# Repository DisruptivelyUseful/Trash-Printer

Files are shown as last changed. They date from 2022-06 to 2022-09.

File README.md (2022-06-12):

# The Trash Printer
The Trash Printer is an open-source, low-cost, large-format 3D printer that prints directly from shredded plastic trash instead of filament.

It has been tested to work with shredded Polypropylene (#5) and Polyethylene (#2 and #4) which together make up over 50% of all household plastic waste. It uses a 1/4" (4.5mm) nozzle, which makes it VERY tolerant of dirt, labels, and adhesives, which are common in post-consumer waste streams.

The parts it makes are incredibly strong, light, and flexible, more comparable in terms of strength to parts made by traditional injection molding processes than those made by most desktop 3D printers. The better you clean your material, the better your prints will look, but if you're lazy like me, you can just throw your trash in without even cleaning it first. Skipping the filament-making step entirely reduces the recycling process to just two steps: Shred, and Print.

# Latest Stable Release
The Trash Printer has been in development for several years, but the most recent release, Version 3, is the first version to be fully open-source, and is easier and cheaper to build than the previous versions. This repository will be the home for the development of V3 onwards.

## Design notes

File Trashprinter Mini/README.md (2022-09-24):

This folder contains all of the unique info for building the Trashprinter Mini, based on the V3 of the Trashprinter.  The Mini uses a smaller cart, which is also available from [Harbor Freight](https://www.harborfreight.com/material-handling/hand-trucks-carts-dollies/service-carts/30-in-x-16-in-industrial-polypropylene-service-cart-58322.html).  All of the STL/SVG parts are the same as the original full-size V3. It's primarily the lead screws that will need to be cut to match the proportions of the smaller service cart frame.

We recently recorded video content showcasing the entire build process of the Mini version.  Edited video will be released in the future, but in the meantime, the raw video content can be seen on our twitch streams at [twitch.tv/DisruptivelyUseful](https://twitch.tv/disruptivelyuseful) and [twitch.tv/Drc3p0](https://twitch.tv/drc3p0)

* The extruder built during the livestream contained a 20mm x 35mm heater band.  [generic link for this part on amazon](https://www.amazon.com/LANGshaw-Stainless-30x25mm-30x30mm-Connector/dp/B0B6WMBQHR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).

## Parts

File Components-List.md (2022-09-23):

| QUANTITY	| 	COMPONENT NAME | LINK/INFO |
| ---- | --- | --- |
|1	|	Polypropylene Service Cart | I used this one from Harbor Freight: https://www.harborfreight.com/material-handling/hand-trucks-carts-dollies/service-carts/36-in-x-24-in-polypropylene-industrial-service-cart-58323.html and this one from Amazon might look nicer, but I haven't confirmed all the dimensions are the same, so proceed with caution: https://www.amazon.com/dp/B00FZ318KS?ref_=cm_sw_r_cp_ud_dp_696WCAM7XY2RMQK0P6MQ |
|1	|	Set of laser-cut or 3D printed parts | See the Build Files - STL or SVG |
| 1	|	15:1 Planetary Geared NEMA23 Stepper Motor | https://www.amazon.com/dp/B00WAV0N5E |
| 1	|	10' 1" OD Metal Tubing (2x24", 2x36") | Stainless Steel or Aluminum preferred. 3/4" EMT conduit will not work without modification of the hole sizes. |
| 4	|	T8 Z-axis Lead Screws | 2mm Pitch, 600mm |
| 2	|	T8 Y-axis Lead Screws | 2mm Pitch, 600mm |
| 1	|	T8 X-axis Lead Screw | 2mm Pitch, 700mm |
| 7	|	T8 Lead Nuts | https://www.amazon.com/gp/product/B079HQ386R |
| 1	|	Set of 4-wire spring connectors | https://www.amazon.com/dp/B08R6TFLHD |
| 1	|	Spool of 4-wire 22ga Stepper Wire | |
| 2	 | 	Series wiring kits from V1Engineering.com | |
| 2	 | 	10A Solid State Relay Modules | https://www.amazon.com/dp/B01N1MMSKI |
| 4	 | 	5/16" Threaded Rods |  |
| 4	 | 	5/16" Coupling Nuts |  |
| 1	 | 	50ct Box of 5/16" x 1" Bolts |  |
| 1	 | 	50ct Box of 5/16" Nuts |  |
| 1	 | 	Ultimaker Rambo v1.4 Control Board Kit |  |
| 1	 | 	Computer, Raspberry Pi, or Laptop | I'm using a Windows 10 Laptop, and if you aren't super confident with computers I'd recommend that, but a Raspberry Pi running Linux or a Mac or Linux laptop can definitely work, I just won't be able to explain exactly how. |
| 1	 | 	Arduino IDE Software |  |
| 1	 | 	Repetier-Host Software |  |
| 1	 | 	USB Extension Cable |  |
| 1	 | 	USB-B cable, 3ft or 6ft |  | https://www.amazon.com/gp/product/B076Z8J141 |
| 7	 | 	NEMA17 Stepper Motors |  https://www.amazon.com/gp/product/B00QEYADRQ |
| 7	 | 	5mm to 8mm Shaft Couplers | https://www.amazon.com/gp/product/B07DC2CV6T |
| 1	 | 	20-pack 608-2RS Bearings |https://www.amazon.com/gp/product/B07TWZ7X38 |
| 30	 | 	M3 Bolts x 20mm |  |
| 16	 | 	M3 Nuts, non-locking |  |
| 1	 | 	M4 x 30mm Bolts |  |
| 1	 | 	M4 Nuts, Nylon Locking |  |
| 8	 | 	5/16" x 2" Bolts | These should come with your service cart. |
| 1	 | 	PVC 3" Plumbing Wye |  |
| 2	 | 	24VDC Fans | https://www.amazon.com/gp/product/B0885XR31J |
| 1	 | 	24VDC 5A Power Supply | https://www.amazon.com/gp/product/B07K9HBHGR |
| 1	 | 	5.5" 3/4" NPT Brass Nipple | https://www.amazon.com/dp/B016Y8EB2E |
| 1	 | 	Gorilla Packing Tape | https://www.amazon.com/dp/B00MR6JWKY |
| 1	 | 	2M USB LED Strip, Warm White | https://www.amazon.com/dp/B08X1QMRKK |
| 1	 | 	Set of 3x 250-300C Cartridge Style Thermistors | https://www.amazon.com/gp/product/B07QDQXDQ5 |
| 1	 | 	35mm x 35mm 110V 380W Heater Band  | This heater works well for sliding over 3/4" NPT pipes and 1/2" NPT fittings. It can be used as a bulk heater or as a tip heater: https://www.amazon.com/gp/product/B075WNXLTY |
| 1	 | 	Set of Lever Lock Connectors | https://www.amazon.com/gp/product/B08QMLSMC6 |
| 1	 | 	10mm to 10mm Shaft Coupler | This is an inelegant but effective solution. I used only one half, and then laser cut a wooden spacer to fit the auger I wanted to use.https://www.amazon.com/gp/product/B078VSM9MG |

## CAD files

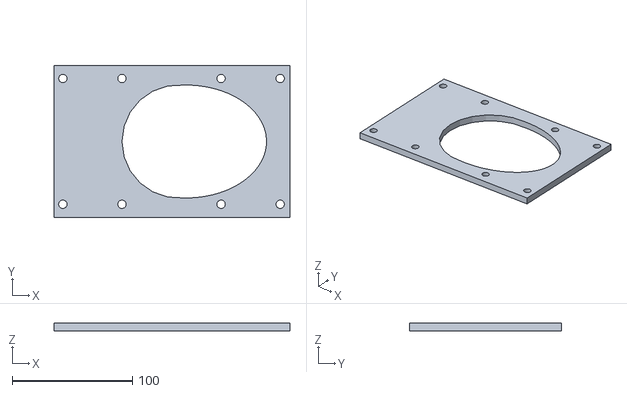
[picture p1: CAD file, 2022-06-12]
Build Files - STL/Trash Printer V3 - X Carriage Top Bracket.stl
196.6 x 126.4 x 6.35

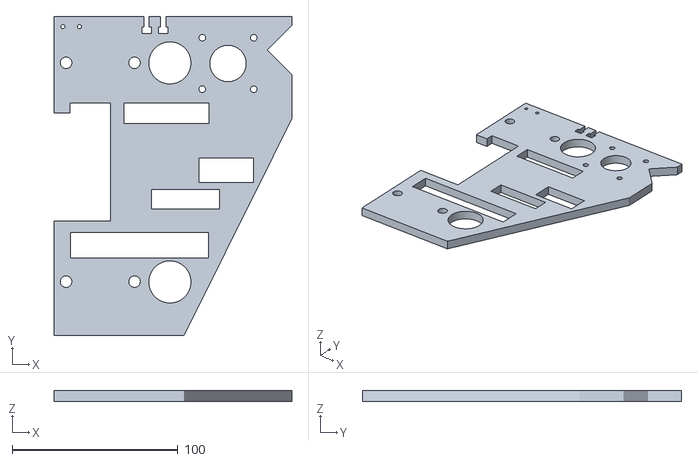
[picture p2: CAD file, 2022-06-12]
Build Files - STL/Trash Printer V3 - X Motor Bracket With Controller Cutouts.stl
143.5 x 192.5 x 6.35

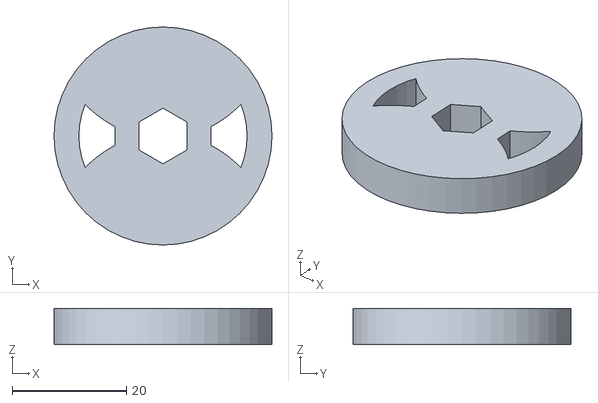
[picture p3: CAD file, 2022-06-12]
Build Files - STL/Trash Printer V3 - Extruder Shaft Coupler 8mm Hex Bit.stl
38.1 x 38.1 x 6.35

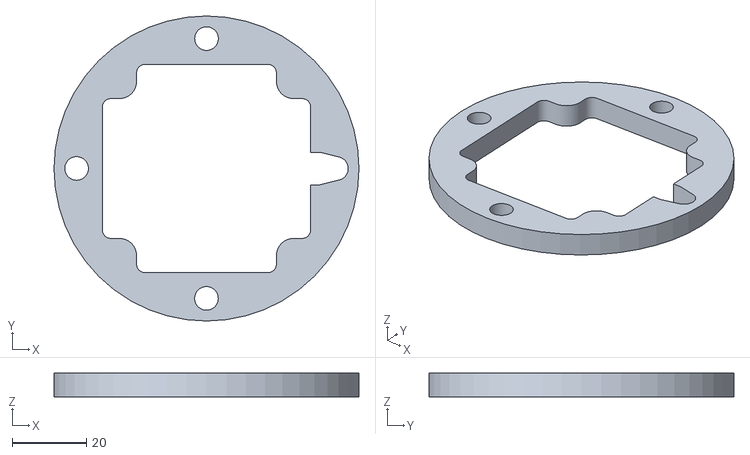
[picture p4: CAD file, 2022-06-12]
Build Files - STL/Trash Printer V3 - Top Extruder Spacer for NEMA23 - T3.stl
82.0 x 82.0 x 6.35

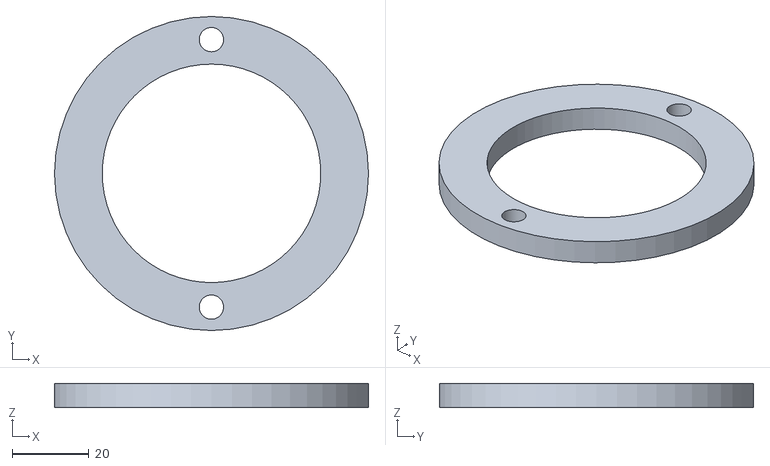
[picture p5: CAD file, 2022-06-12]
Build Files - STL/Trash Printer V3 - Top Extruder Spacer for NEMA23 - T2.stl
82.0 x 82.0 x 6.35

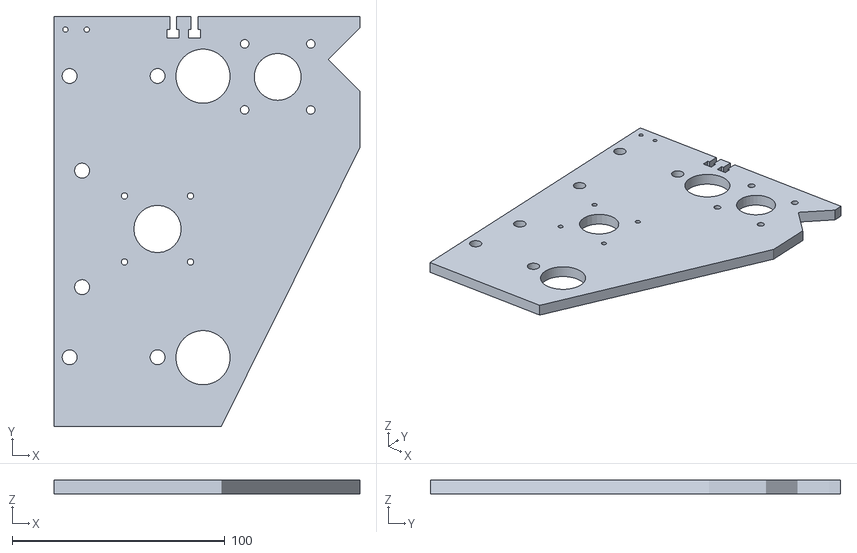
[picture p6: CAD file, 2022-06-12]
Build Files - STL/Trash Printer V3 - X Motor Bracket.stl
143.5 x 192.5 x 6.35

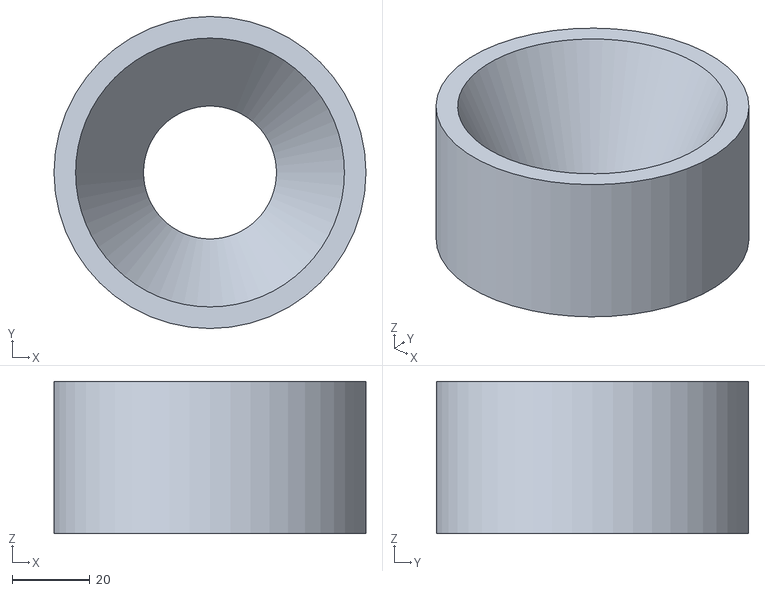
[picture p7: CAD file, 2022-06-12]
Build Files - STL/Trash Printer V3- Trash Printable Lower Funnel.stl
80.4 x 80.4 x 39.2

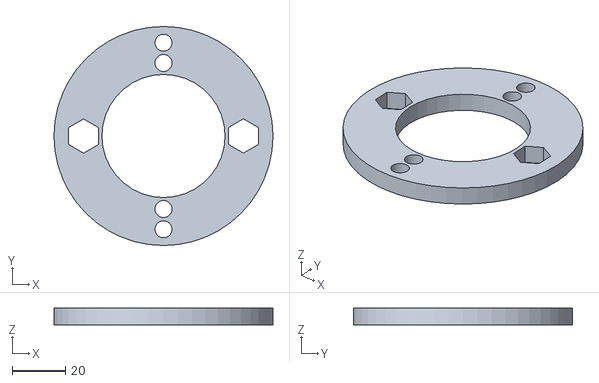
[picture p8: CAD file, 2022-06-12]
Build Files - STL/Trash Printer V3 - Lower Extruder Spacer B5.stl
82.0 x 82.0 x 6.35

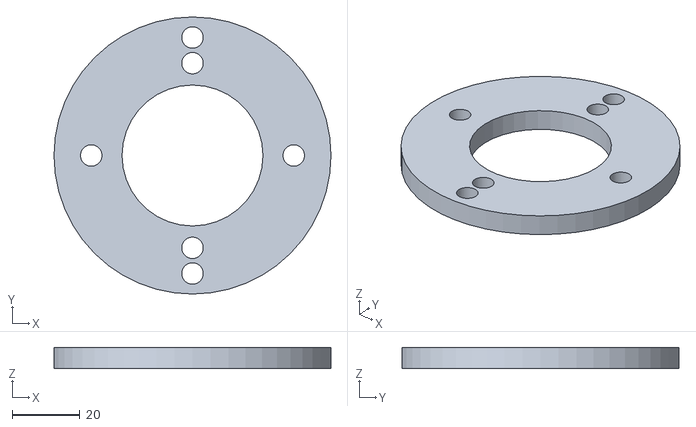
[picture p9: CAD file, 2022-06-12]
Build Files - STL/Trash Printer V3 - Lower Extruder Spacer B4.stl
82.0 x 82.0 x 6.35

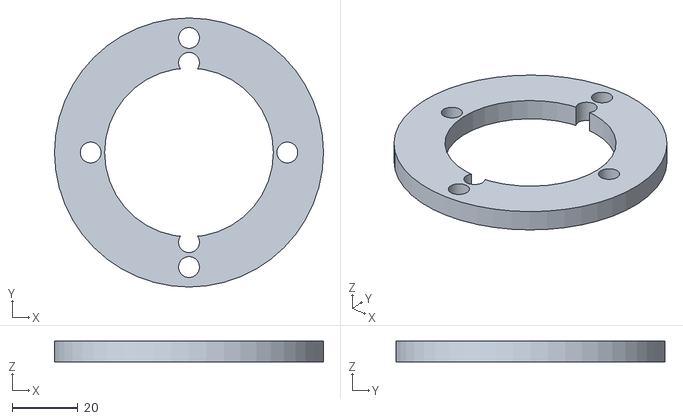
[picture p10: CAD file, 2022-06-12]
Build Files - STL/Trash Printer V3 - Lower Extruder Spacer B6.stl
82.0 x 82.0 x 6.35

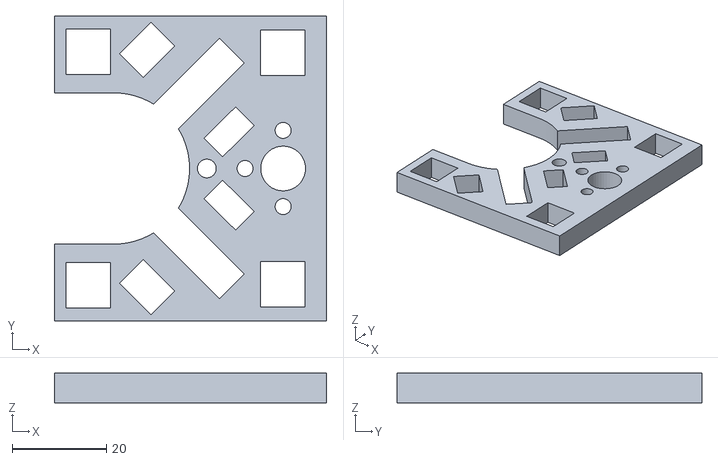
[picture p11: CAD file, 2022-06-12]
Build Files - STL/Trash Printer V3 - Roller Bracket.stl
57.9 x 64.8 x 6.35

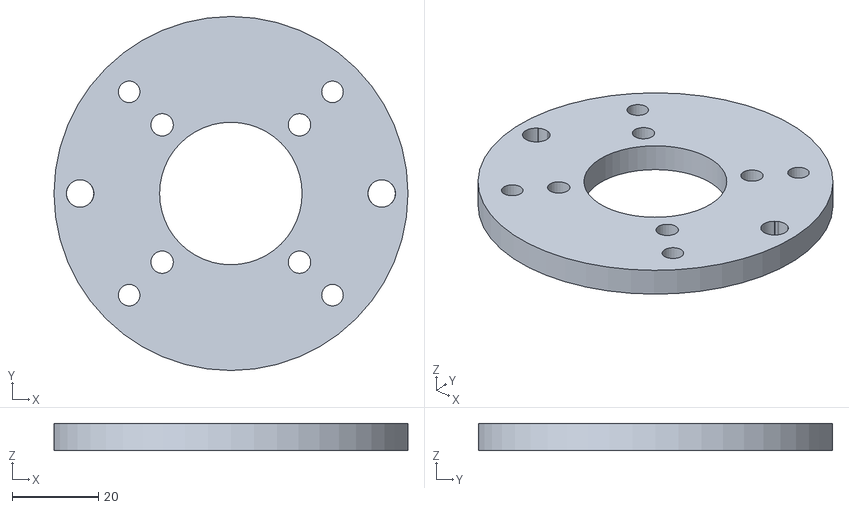
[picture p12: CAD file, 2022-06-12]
Build Files - STL/Trash Printer V3 - Top Extruder Spacer for NEMA23 - T1.stl
82.0 x 82.0 x 6.35

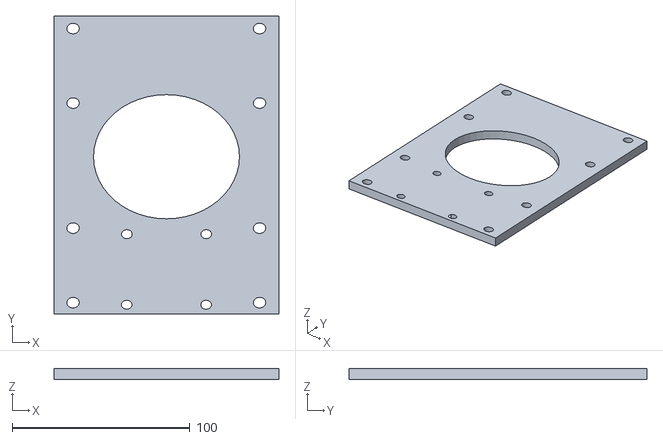
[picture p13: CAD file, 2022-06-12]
Build Files - STL/Trash Printer V3 - X Carriage Bottom Bracket.stl
126.4 x 167.2 x 6.35

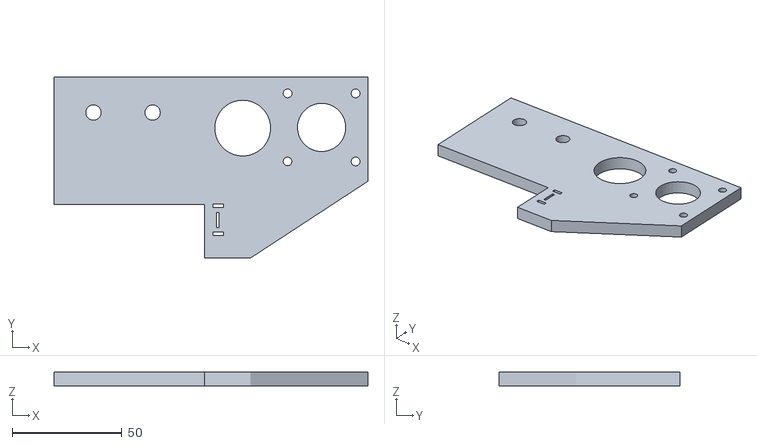
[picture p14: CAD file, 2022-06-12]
Build Files - STL/Trash Printer V3 - Y Motor Bracket.stl
143.1 x 82.5 x 6.35

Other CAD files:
Build Files - STL/Trash Printer V3 - Lower Extruder Spacer B3.stl
Build Files - STL/Trash Printer V3 - Lower Extruder Spacer B2.stl
Build Files - STL/Trash Printer V3 - Lower Extruder Spacer B7.stl
Build Files - STL/Trash Printer V3 - Lower Extruder Spacer B1.stl
Build Files - STL/Trash Printer V3 - Z Motor Bracket.stl

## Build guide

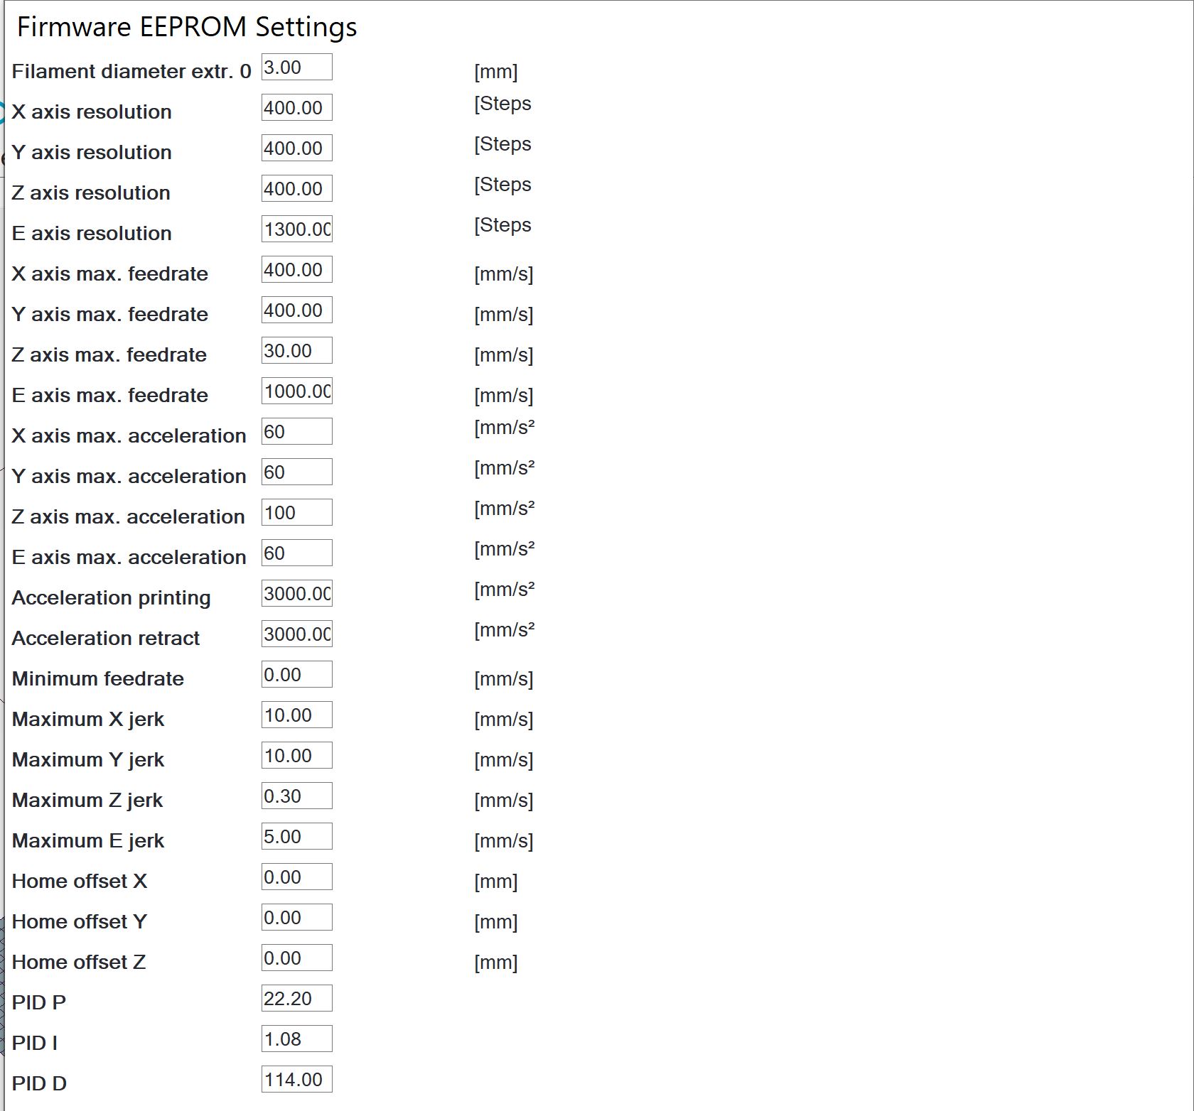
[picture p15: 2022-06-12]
Software and Firmware/Printer and Slic3r Settings/Firmware EEPROM Settings.JPG

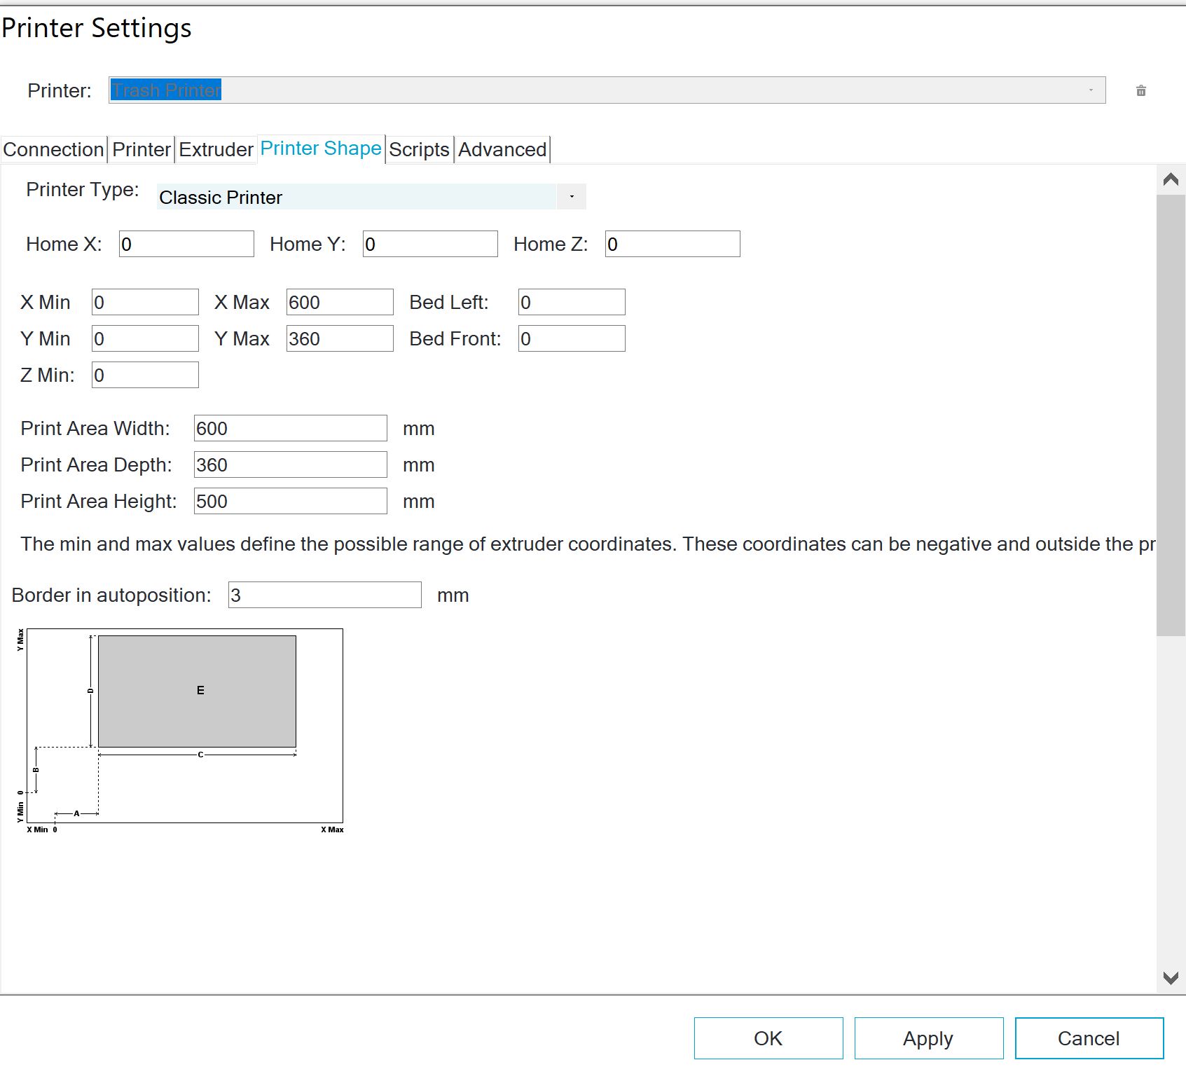
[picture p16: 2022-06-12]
Software and Firmware/Printer and Slic3r Settings/Printer Settings.JPG

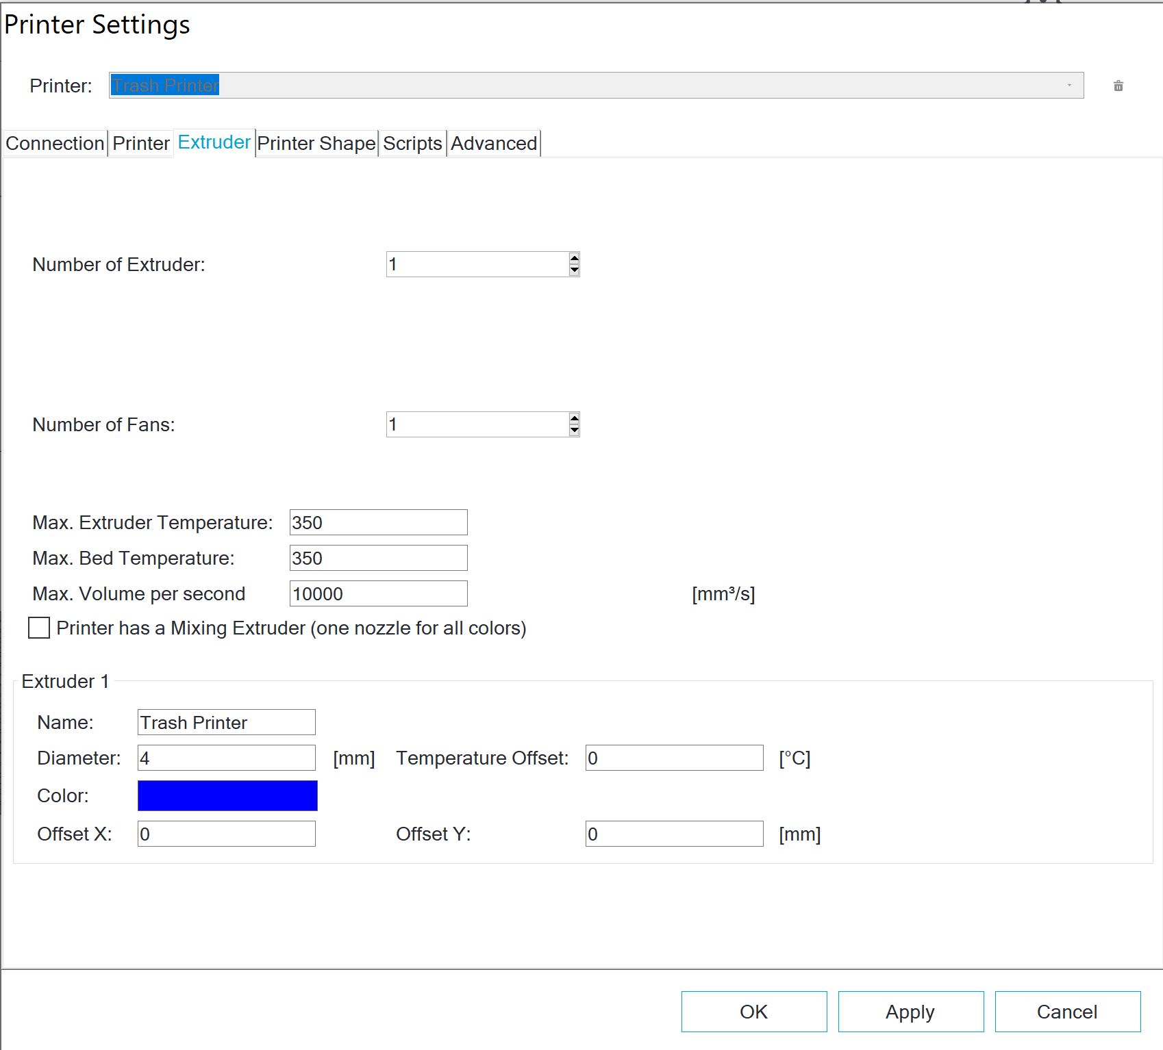
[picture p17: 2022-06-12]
Software and Firmware/Printer and Slic3r Settings/Printer Settings - Extruder.JPG

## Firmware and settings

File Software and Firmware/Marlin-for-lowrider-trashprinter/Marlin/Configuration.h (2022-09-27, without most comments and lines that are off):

#pragma once
#define CONFIGURATION_H_VERSION 020005
#define STRING_CONFIG_H_AUTHOR "(V1 Engineering, Ryan, 426)" // Who made the changes.
#define SHOW_BOOTSCREEN
#define SHOW_CUSTOM_BOOTSCREEN
#define SERIAL_PORT 0
#define BAUDRATE 250000
#define MOTHERBOARD BOARD_RAMBO
#define CUSTOM_MACHINE_NAME "TrashPrinter" //changed by DRC
#define EXTRUDERS 1 //changed by DRC
#define DEFAULT_NOMINAL_FILAMENT_DIA 5.0 //changed by DRC
#define TEMP_SENSOR_0 1 //barrel heater band
#define TEMP_SENSOR_1 0
#define TEMP_SENSOR_2 0
#define TEMP_SENSOR_3 0
#define TEMP_SENSOR_4 0
#define TEMP_SENSOR_5 0
#define TEMP_SENSOR_6 0
#define TEMP_SENSOR_7 0
#define TEMP_SENSOR_BED 11 //hotend
#define TEMP_SENSOR_PROBE 0
#define TEMP_SENSOR_CHAMBER 1 //ambient air temp
#define DUMMY_THERMISTOR_998_VALUE 25
#define DUMMY_THERMISTOR_999_VALUE 170
#define MAX_REDUNDANT_TEMP_SENSOR_DIFF 10
#define TEMP_RESIDENCY_TIME     10  // (seconds) Time to wait for hotend to "settle" in M109
#define TEMP_WINDOW              1  // (°C) Temperature proximity for the "temperature reached" timer
#define TEMP_HYSTERESIS          3  // (°C) Temperature proximity considered "close enough" to the target
#define TEMP_BED_RESIDENCY_TIME 10  // (seconds) Time to wait for bed to "settle" in M190
#define TEMP_BED_WINDOW          1  // (°C) Temperature proximity for the "temperature reached" timer
#define TEMP_BED_HYSTERESIS      3  // (°C) Temperature proximity considered "close enough" to the target
#define HEATER_0_MINTEMP   15 //all changed from 5 to 15 by DRC
#define HEATER_1_MINTEMP   15
#define HEATER_2_MINTEMP   15
#define HEATER_3_MINTEMP   15
#define HEATER_4_MINTEMP   15
#define HEATER_5_MINTEMP   15
#define HEATER_6_MINTEMP   15
#define HEATER_7_MINTEMP   15
#define BED_MINTEMP        15
#define HEATER_0_MAXTEMP 275
#define HEATER_1_MAXTEMP 275
#define HEATER_2_MAXTEMP 275
#define HEATER_3_MAXTEMP 275
#define HEATER_4_MAXTEMP 275
#define HEATER_5_MAXTEMP 275
#define HEATER_6_MAXTEMP 275
#define HEATER_7_MAXTEMP 275
#define BED_MAXTEMP      150
#define PIDTEMP
#define BANG_MAX 255     // Limits current to nozzle while in bang-bang mode; 255=full current
#define PID_MAX BANG_MAX // Limits current to nozzle while PID is active (see PID_FUNCTIONAL_RANGE below); 255=full current
#define PID_K1 0.95      // Smoothing factor within any PID loop
#define PID_FUNCTIONAL_RANGE 10 // If the temperature difference between the target temperature and the actual temperature
#define DEFAULT_Kp 22.2
#define DEFAULT_Ki 1.08
#define DEFAULT_Kd 114
#define MAX_BED_POWER 255 // limits duty cycle to bed; 255=full current
#define PREVENT_COLD_EXTRUSION
#define EXTRUDE_MINTEMP 170
#define PREVENT_LENGTHY_EXTRUDE
#define EXTRUDE_MAXLENGTH 200
#define THERMAL_PROTECTION_HOTENDS // Enable thermal protection for all extruders
#define THERMAL_PROTECTION_BED     // Enable thermal protection for the heated bed
#define THERMAL_PROTECTION_CHAMBER // Enable thermal protection for the heated chamber
#define USE_XMIN_PLUG
#define USE_YMIN_PLUG
#define USE_ZMIN_PLUG
#define ENDSTOPPULLUPS
#define X_MIN_ENDSTOP_INVERTING true // Set to true to invert the logic of the endstop.
#define Y_MIN_ENDSTOP_INVERTING true // Set to true to invert the logic of the endstop.
#define Z_MIN_ENDSTOP_INVERTING true // Set to true to invert the logic of the endstop.
#define X_MAX_ENDSTOP_INVERTING false // Set to true to invert the logic of the endstop.
#define Y_MAX_ENDSTOP_INVERTING false // Set to true to invert the logic of the endstop.
#define Z_MAX_ENDSTOP_INVERTING false // Set to true to invert the logic of the endstop.
#define Z_MIN_PROBE_ENDSTOP_INVERTING true // Set to true to invert the logic of the probe.
#define DEFAULT_AXIS_STEPS_PER_UNIT   { 100, 100, 400, 100 }  //sams was 80, 80, 4000, 500
#define DEFAULT_MAX_FEEDRATE          { 50, 50, 15, 25 }  //sams was 300, 300, 5, 25
#define DEFAULT_MAX_ACCELERATION      { 180, 180, 80, 180 } //sams was 3000, 3000, 100, 10000
#define DEFAULT_ACCELERATION          180  //sams was 3000   // X, Y, Z and E acceleration for printing moves
#define DEFAULT_RETRACT_ACCELERATION  3000 //sams was 3000   // E acceleration for retracts
#define DEFAULT_TRAVEL_ACCELERATION   180 //sams was 3000   // X, Y, Z acceleration for travel (non printing) moves
#define DEFAULT_EJERK    5.0  // May be used by Linear Advance
#define JUNCTION_DEVIATION_MM 0.04 // (mm) Distance from real junction edge
#define S_CURVE_ACCELERATION
#define NOZZLE_TO_PROBE_OFFSET { 10, 10, 0 }
#define MIN_PROBE_EDGE 10
#define XY_PROBE_SPEED 8000
#define Z_PROBE_SPEED_FAST HOMING_FEEDRATE_Z
#define Z_PROBE_SPEED_SLOW (Z_PROBE_SPEED_FAST / 2)
#define Z_CLEARANCE_DEPLOY_PROBE   10 // Z Clearance for Deploy/Stow
#define Z_CLEARANCE_BETWEEN_PROBES  5 // Z Clearance between probe points
#define Z_CLEARANCE_MULTI_PROBE     5 // Z Clearance between multiple probes
#define Z_PROBE_LOW_POINT          -2 // Farthest distance below the trigger-point to go before stopping
#define Z_PROBE_OFFSET_RANGE_MIN -20
#define Z_PROBE_OFFSET_RANGE_MAX 20
#define X_ENABLE_ON 0
#define Y_ENABLE_ON 0
#define Z_ENABLE_ON 0
#define E_ENABLE_ON 0 // For all extruders
#define DISABLE_X false
#define DISABLE_Y false
#define DISABLE_Z false
#define DISABLE_E false             // For all extruders
#define DISABLE_INACTIVE_EXTRUDER   // Keep only the active extruder enabled
#define INVERT_X_DIR false
#define INVERT_Y_DIR true
#define INVERT_Z_DIR false
#define INVERT_E0_DIR false
#define INVERT_E1_DIR false
#define INVERT_E2_DIR false
#define INVERT_E3_DIR false
#define INVERT_E4_DIR false
#define INVERT_E5_DIR false
#define INVERT_E6_DIR false
#define INVERT_E7_DIR false
#define X_HOME_DIR -1
#define Y_HOME_DIR -1
#define Z_HOME_DIR -1
#define X_BED_SIZE 200
#define Y_BED_SIZE 200
#define X_MIN_POS 0
#define Y_MIN_POS 0
#define Z_MIN_POS 0
#define X_MAX_POS X_BED_SIZE
#define Y_MAX_POS Y_BED_SIZE
#define Z_MAX_POS 200
#define HOMING_FEEDRATE_XY (30*60)
#define HOMING_FEEDRATE_Z  (3*60)
#define VALIDATE_HOMING_ENDSTOPS
#define EEPROM_SETTINGS     // Persistent storage with M500 and M501
#define EEPROM_CHITCHAT       // Give feedback on EEPROM commands. Disable to save PROGMEM.
#define EEPROM_BOOT_SILENT    // Keep M503 quiet and only give errors during first load
#define EEPROM_AUTO_INIT  // Init EEPROM automatically on any errors.
#define HOST_KEEPALIVE_FEATURE        // Disable this if your host doesn't like keepalive messages
#define DEFAULT_KEEPALIVE_INTERVAL 2  // Number of seconds between "busy" messages. Set with M113.
#define BUSY_WHILE_HEATING            // Some hosts require "busy" messages even during heating
#define PREHEAT_1_LABEL       "PLA"
#define PREHEAT_1_TEMP_HOTEND 180
#define PREHEAT_1_TEMP_BED     70
#define PREHEAT_1_FAN_SPEED     0 // Value from 0 to 255
#define PREHEAT_2_LABEL       "PP"
#define PREHEAT_2_TEMP_HOTEND 260  //modified for PP by DRC (how to add second heater?)
#define PREHEAT_2_TEMP_BED    70
#define PREHEAT_2_FAN_SPEED     0 // Value from 0 to 255
#define PRINTJOB_TIMER_AUTOSTART
#define LCD_LANGUAGE en
#define DISPLAY_CHARSET_HD44780 JAPANESE
#define LCD_INFO_SCREEN_STYLE 0
#define SDSUPPORT
#define REVERSE_ENCODER_DIRECTION
#define REPRAP_DISCOUNT_FULL_GRAPHIC_SMART_CONTROLLER
#define SOFT_PWM_SCALE 0
#define SERVO_DELAY { 300 }

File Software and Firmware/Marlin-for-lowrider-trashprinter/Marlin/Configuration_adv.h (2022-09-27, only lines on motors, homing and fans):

#define E0_AUTO_FAN_PIN -1
#define E1_AUTO_FAN_PIN -1
#define E2_AUTO_FAN_PIN -1
#define E3_AUTO_FAN_PIN -1
#define E4_AUTO_FAN_PIN -1
#define E5_AUTO_FAN_PIN -1
#define CHAMBER_AUTO_FAN_PIN -1
#define X_HOME_BUMP_MM 5
#define Y_HOME_BUMP_MM 5
#define Z_HOME_BUMP_MM 2
#define HOMING_BUMP_DIVISOR { 2, 2, 4 }  // Re-Bump Speed Divisor (Divides the Homing Feedrate)
#define MICROSTEP_MODES { 16, 16, 16, 16, 16, 16 } // [1,2,4,8,16]
#define DIGIPOT_MOTOR_CURRENT { 138,138,138,138,138 }   // Values 0-255 (RAMBO 135 = ~0.75A, 185 = ~1A)
#define DIGIPOT_I2C_MOTOR_CURRENTS { 1.0, 1.0, 1.0, 1.0, 1.0, 1.0, 1.0, 1.0 }  //  AZTEEG_X3_PRO

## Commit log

2022-06-12 Initial Upload of Build Files
    [Configuration.h, Configuration_adv.h, Trash Printer V3 - Extruder Shaft Coupler 8mm Hex Bit.stl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]
2022-09-27 deleted placeholder marlin files, uploaded marlin files from Drcs trashprinter build
    [Configuration.h, Configuration_adv.h]
2022-09-27 updating with stable marlin release
    [Configuration.h, Configuration_adv.h, esp32.csv]

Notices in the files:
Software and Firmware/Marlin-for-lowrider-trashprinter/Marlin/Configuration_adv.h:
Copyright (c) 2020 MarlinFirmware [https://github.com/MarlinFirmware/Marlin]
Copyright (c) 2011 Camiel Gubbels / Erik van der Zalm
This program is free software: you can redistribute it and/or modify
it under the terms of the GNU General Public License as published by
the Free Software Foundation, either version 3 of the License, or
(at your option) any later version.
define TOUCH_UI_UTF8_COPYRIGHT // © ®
